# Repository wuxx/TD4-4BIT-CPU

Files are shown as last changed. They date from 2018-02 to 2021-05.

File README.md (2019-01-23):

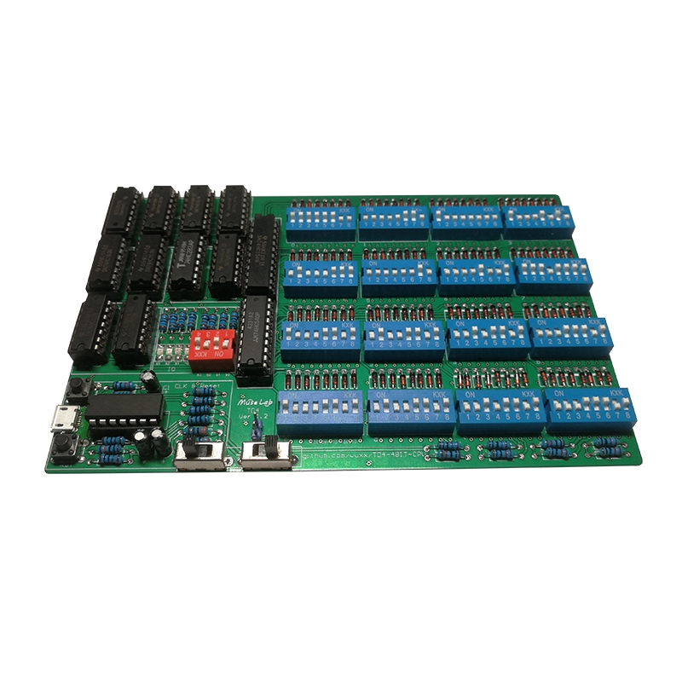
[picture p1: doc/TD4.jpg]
TD4


#### [自己动手做CPU 之 TD4 前言](https://www.bilibili.com/video/av19607028/) ####
#### [自己动手做CPU 之 TD4 原理分析0-系统综述](https://www.bilibili.com/video/av19608406/) ####
#### [自己动手做CPU 之 TD4 原理分析1-[时钟、复位]](https://www.bilibili.com/video/av19609356/) ####
#### [自己动手做CPU 之 TD4 原理分析2-[存储器、输入、输出]](https://www.bilibili.com/video/av19637295/) ####
#### [自己动手做CPU 之 TD4 原理分析3-[控制器、运算器]](https://www.bilibili.com/video/av19640430/) ####
\#LOAD0 = D6 | D7  
\#LOAD1 = #D6 | D7  
\#LOAD2 = #(#D6 & D7)  
\#LOAD3 = #(D6 & D7 & (#C | D4))  
SEL_A   = D4 | D7  
SEL_B   = D5

#### [自己动手做CPU 之 TD4 PCB及元器件](https://www.bilibili.com/video/av20360412/) ####
#### [自己动手做CPU 之 TD4 焊接测试0-说明](https://www.bilibili.com/video/av20396047/) ####
A.  先焊接尺寸小，低的元器件，再焊接高的元器件，推荐焊接顺序如下:  
    1. 发光LED，二极管1N4148，直插电阻，USB接口。  
    2. IC插座  
    3. 8位拨码开关、4位拨码开关  
    4. 按键开关，电解电容，拨动开关  

B.  注意芯片插座，8位拨码开关和4位拨码开关的焊接方向  
#### [自己动手做CPU 之 TD4 焊接测试1-[焊接]](https://www.bilibili.com/video/av20396487/) ####
#### [自己动手做CPU 之 TD4 焊接测试2-[测试]](https://www.bilibili.com/video/av20400512/) ####

#### [自己动手做CPU 之 TD4 后记](https://www.bilibili.com/video/av20401635/) ####
架构  
1. RAM  
2. 4bit -> 8bit  
3. ALU  
4. 中断  

指令  
1. 算术逻辑指令  
2. 寻址方式（立即数寻址、相对寻址、寄存器寻址等）  
3. call push pop  

reference0:  
[指令格式](https://github.com/wuxx/TD4-4BIT-CPU/blob/master/doc/instruction.md)  
[TD4套件](https://item.taobao.com/item.htm?spm=a1z10.1-c-s.w4004-21291591846.20.3ee420f8z442NM&id=586081308296)

reference1:  
https://hackaday.io/project/8442-ttl-based-4-bit-cpu  
https://hackaday.io/project/26215-td4-cpu  
http://kamakurium.com/wp-content/uploads/2016/01/cpu_td4  
http://visual6502.org/  
http://www.4004.com/

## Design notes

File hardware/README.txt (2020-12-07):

v1.3
阻焊改成黑色

v1.4
283 C0引脚默认拉低至GND，因为部分283芯片C0悬空时候会判定为1，加法运算时候会加上这个进位，导致运算错误。

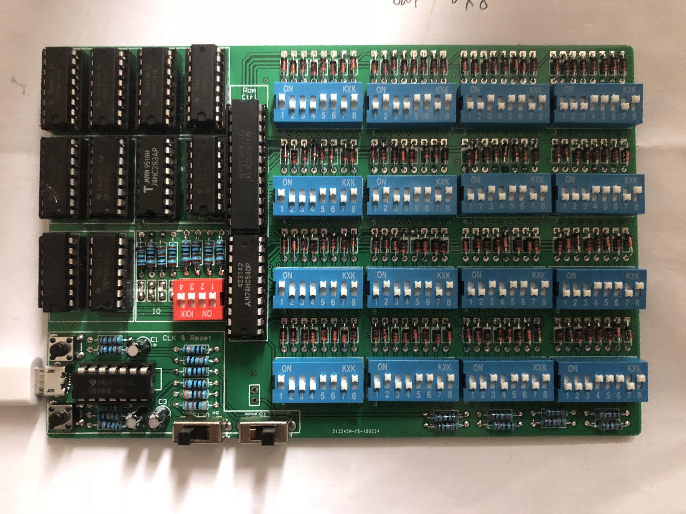
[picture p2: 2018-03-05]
doc/PCB/kit1.jpg

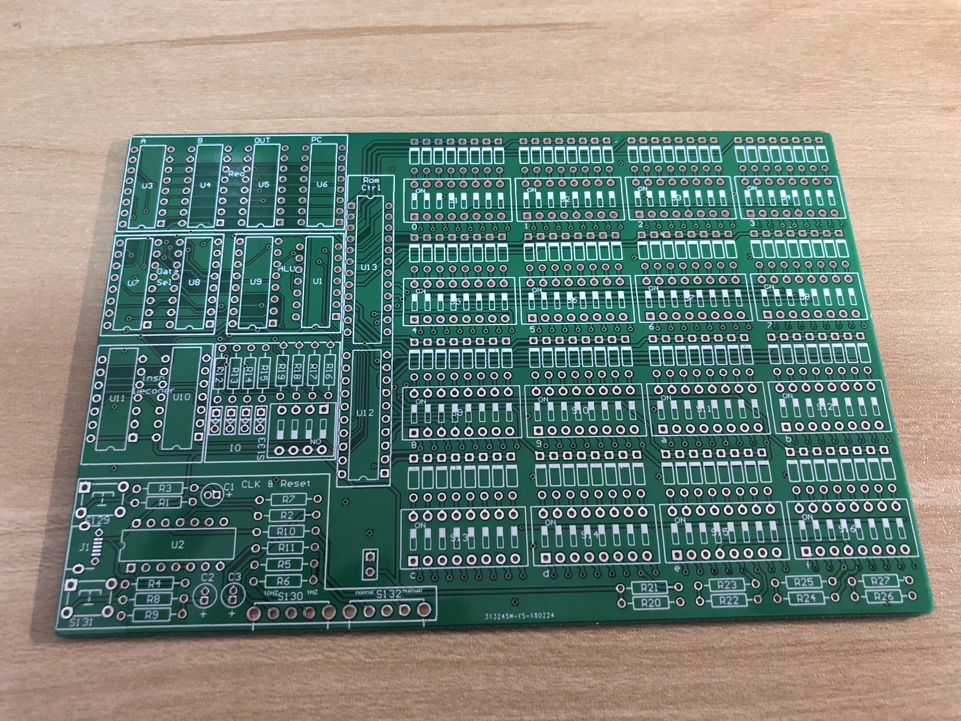
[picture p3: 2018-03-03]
doc/PCB/top.JPG

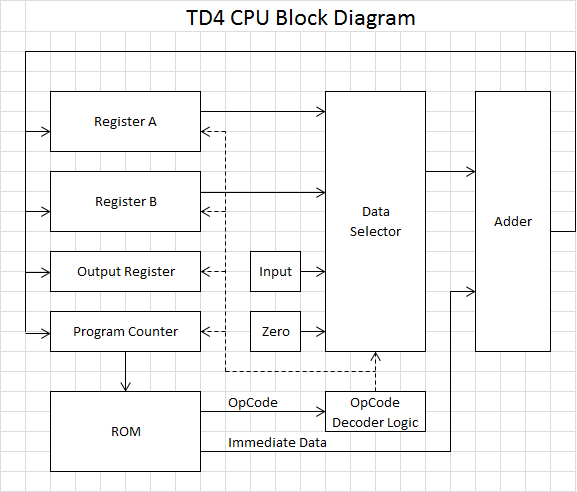
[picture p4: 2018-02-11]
doc/block diagram.png

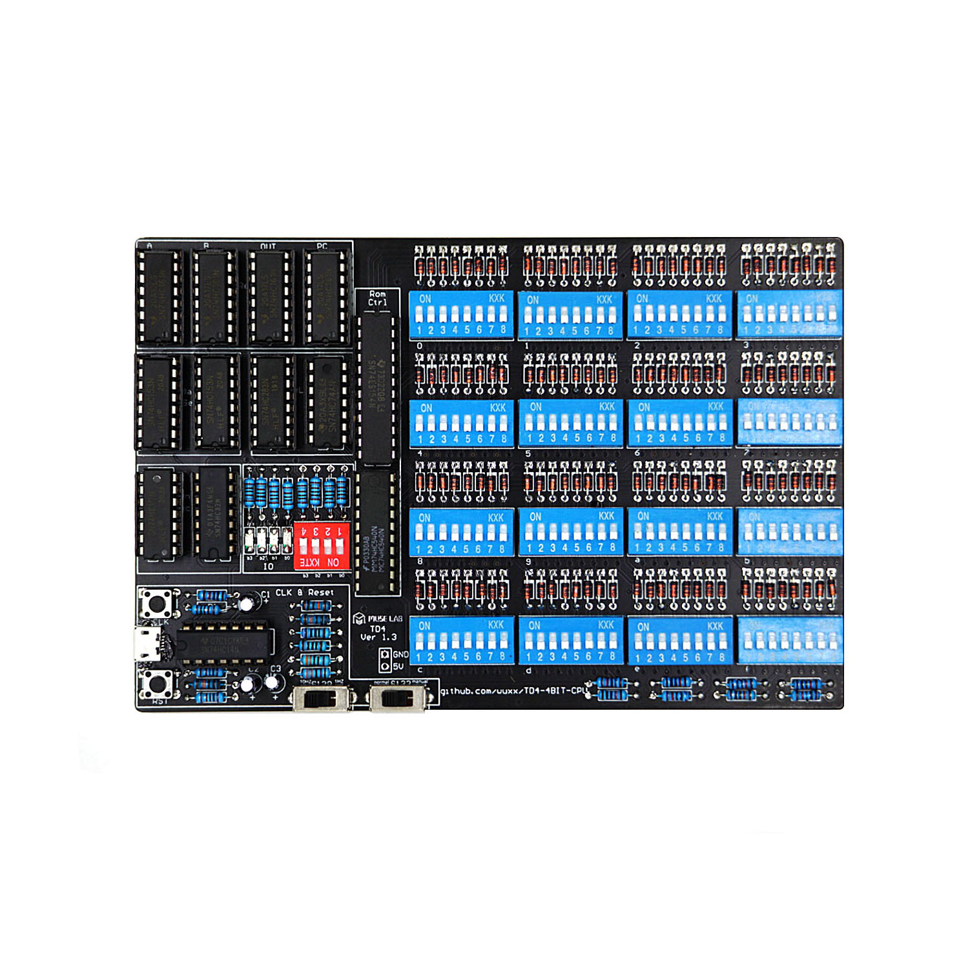
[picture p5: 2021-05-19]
doc/TD4-black-1.jpg

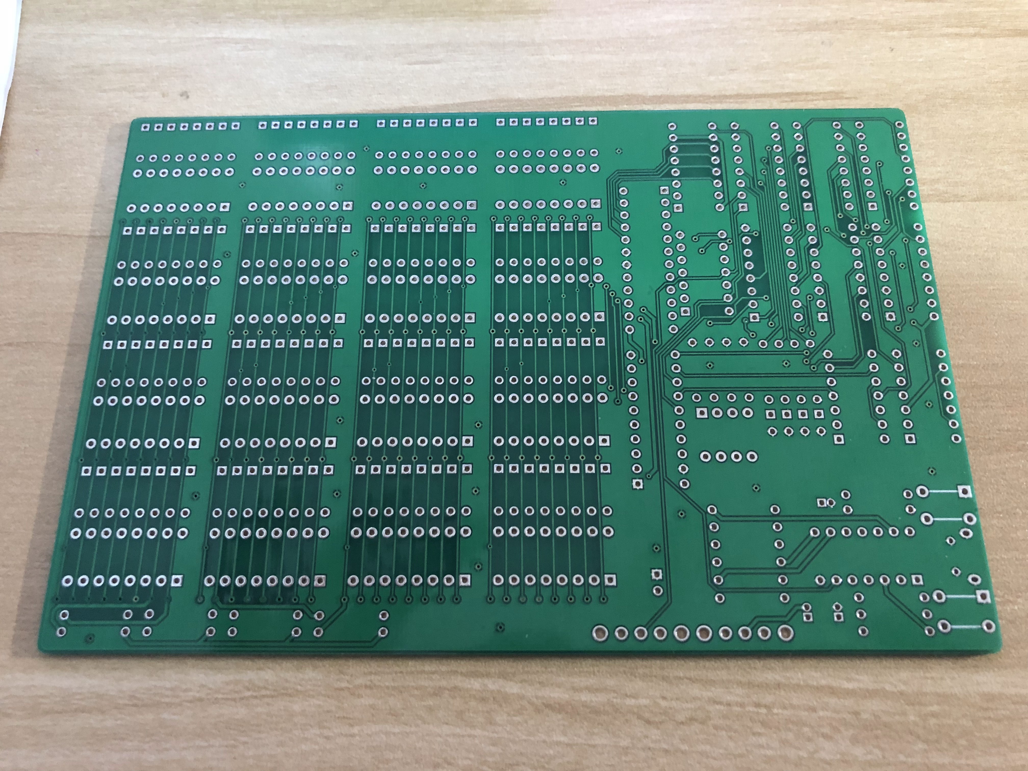
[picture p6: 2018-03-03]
doc/PCB/bottom.JPG

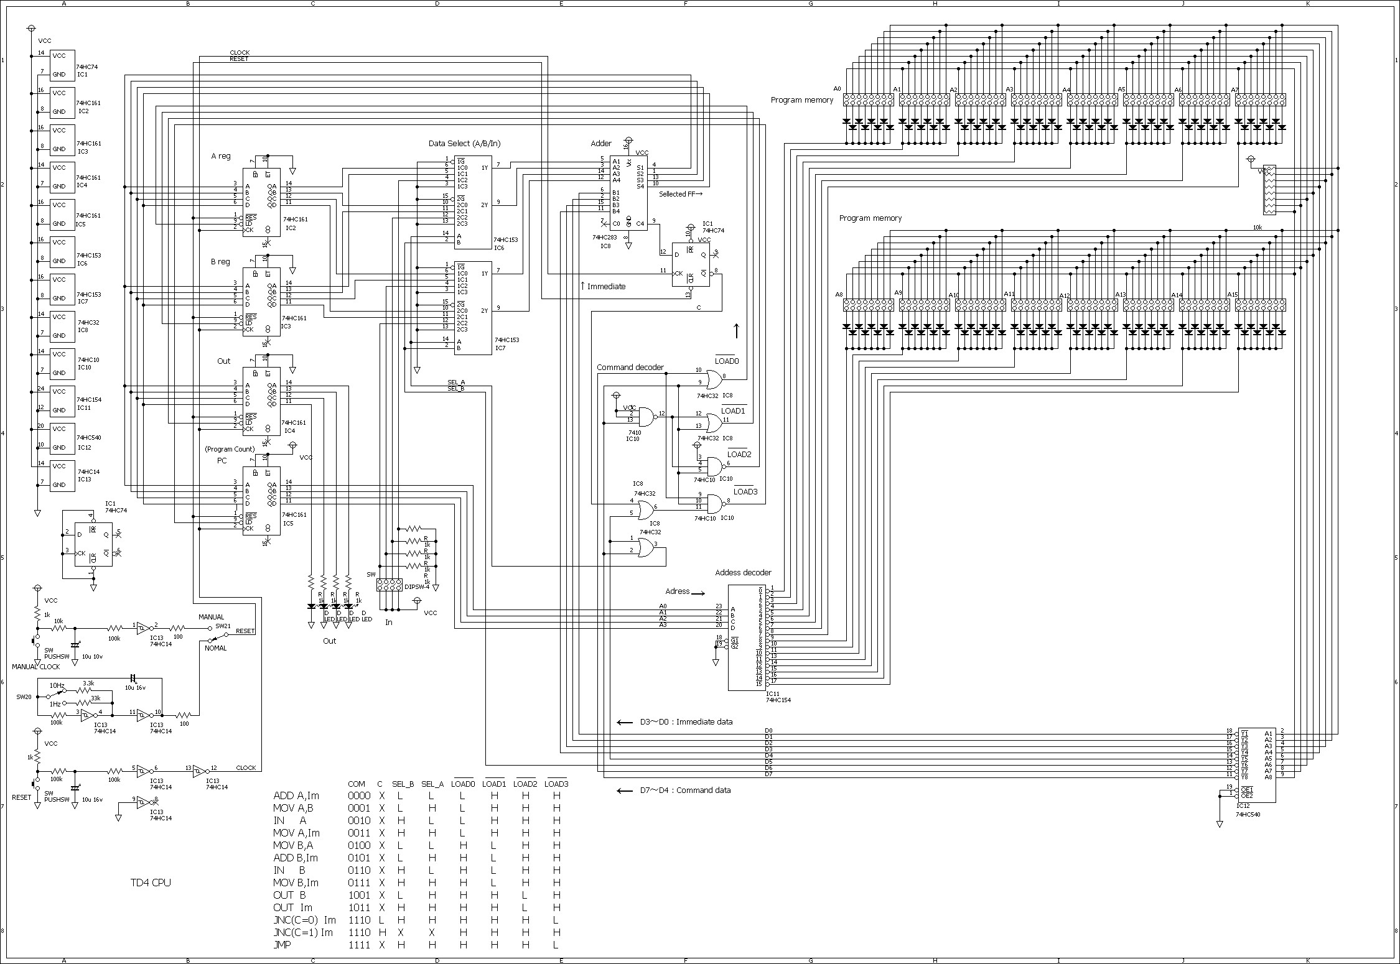
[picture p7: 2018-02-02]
doc/cpu_td4.jpg

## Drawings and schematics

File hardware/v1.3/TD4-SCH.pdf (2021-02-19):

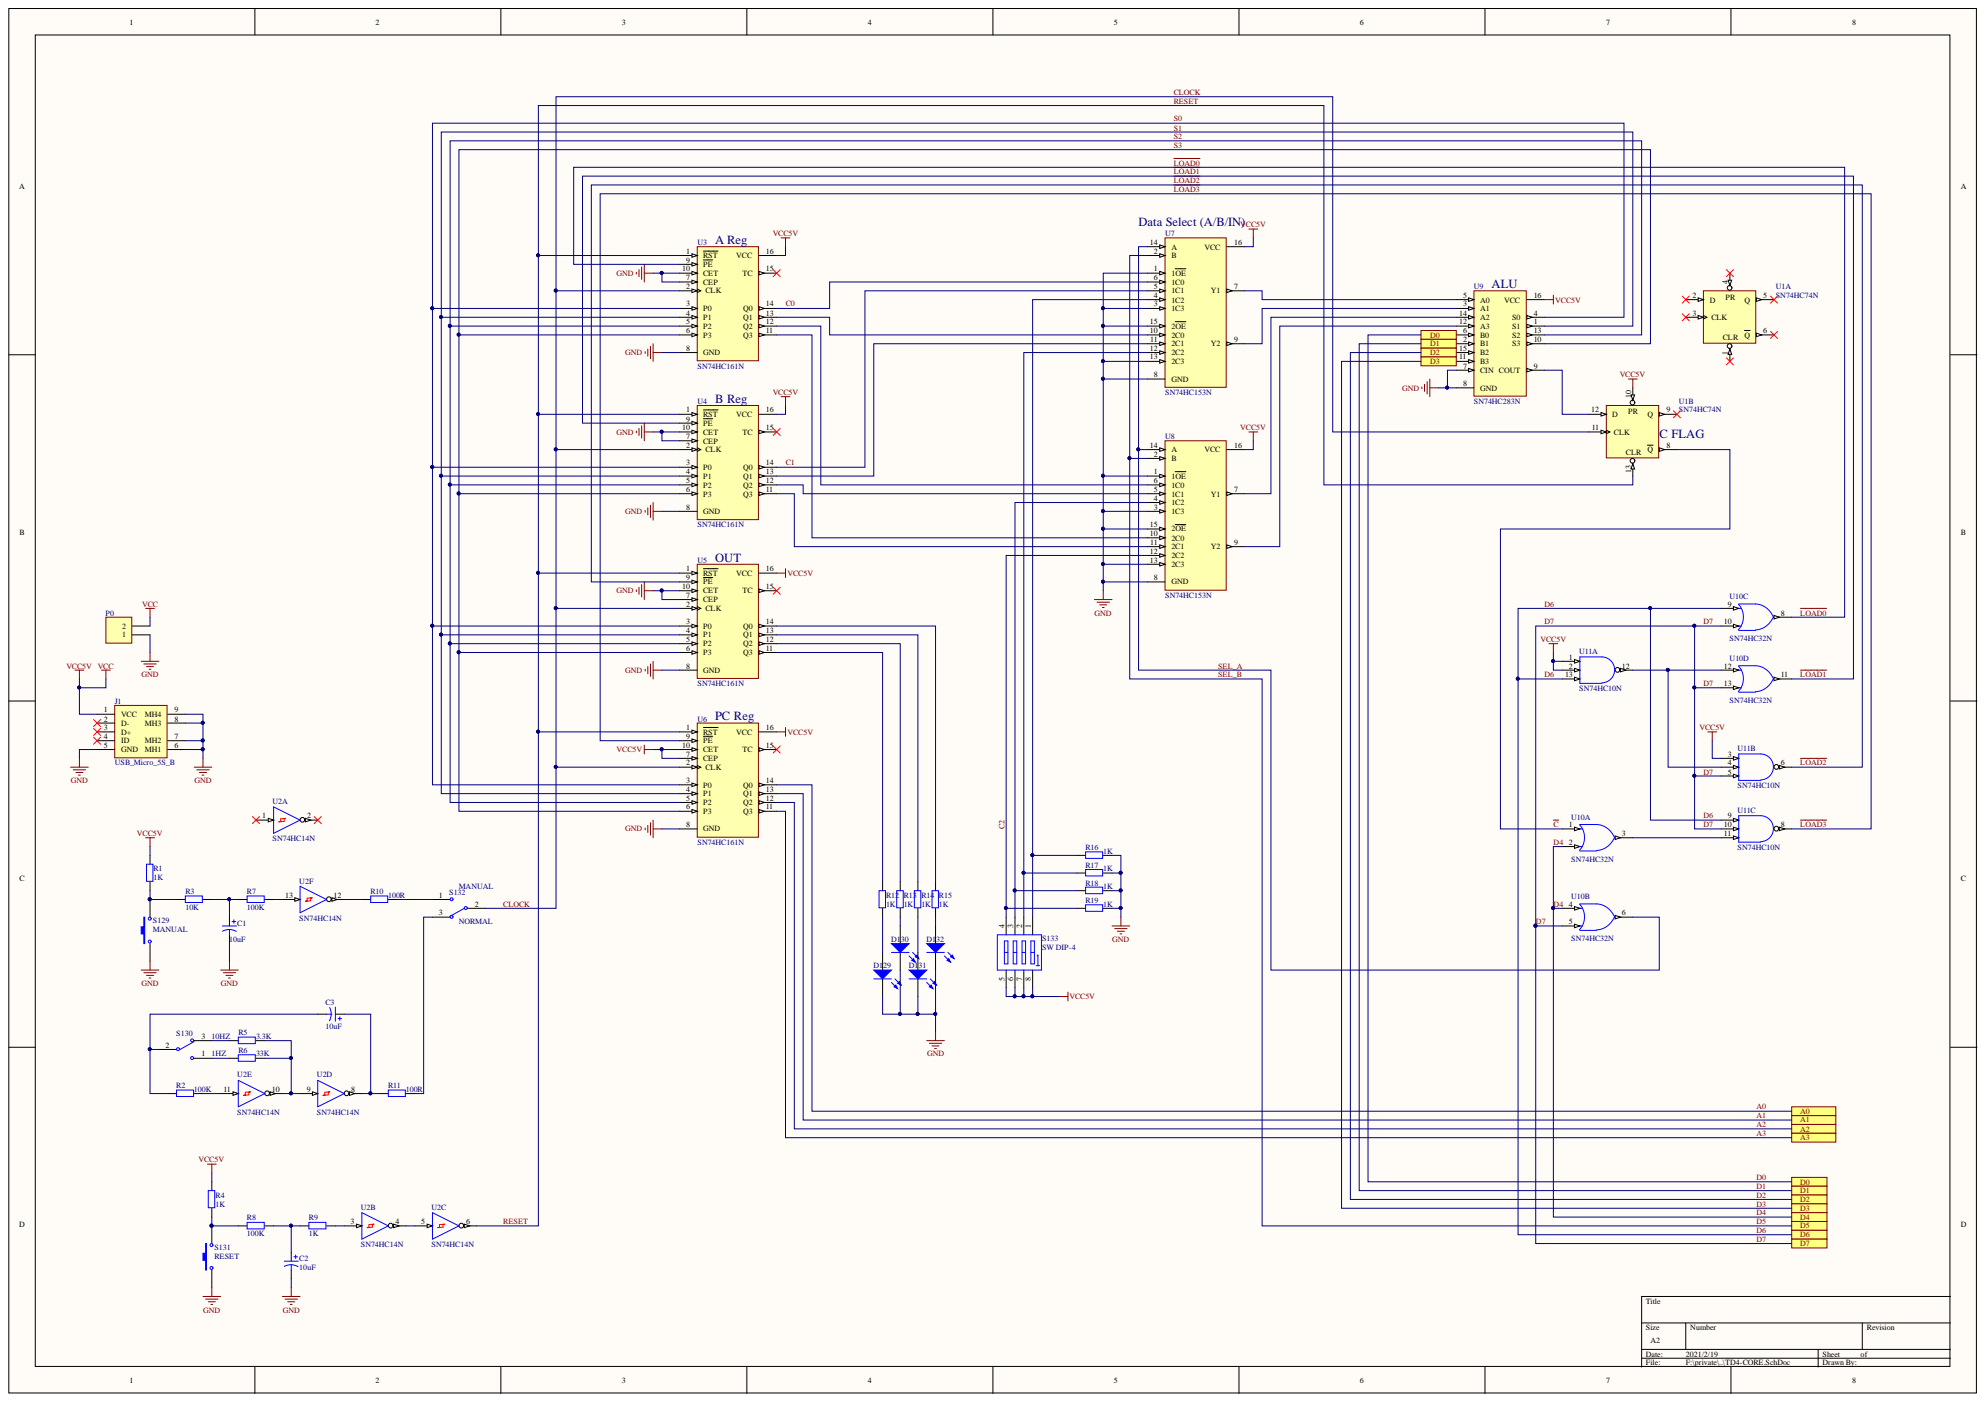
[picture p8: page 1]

S0
S1
S2
S3

LOAD0
LOAD1
LOAD2
LOAD3

Data Select (A/B/IN) VCC5V VCC5V U7 | U9 ALU

CET 10

2C1 11
2C2 12 SEL_A
2C3 13

GND 8 | 1K R16 | C 1 3 | D6 | U11C 9 8

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
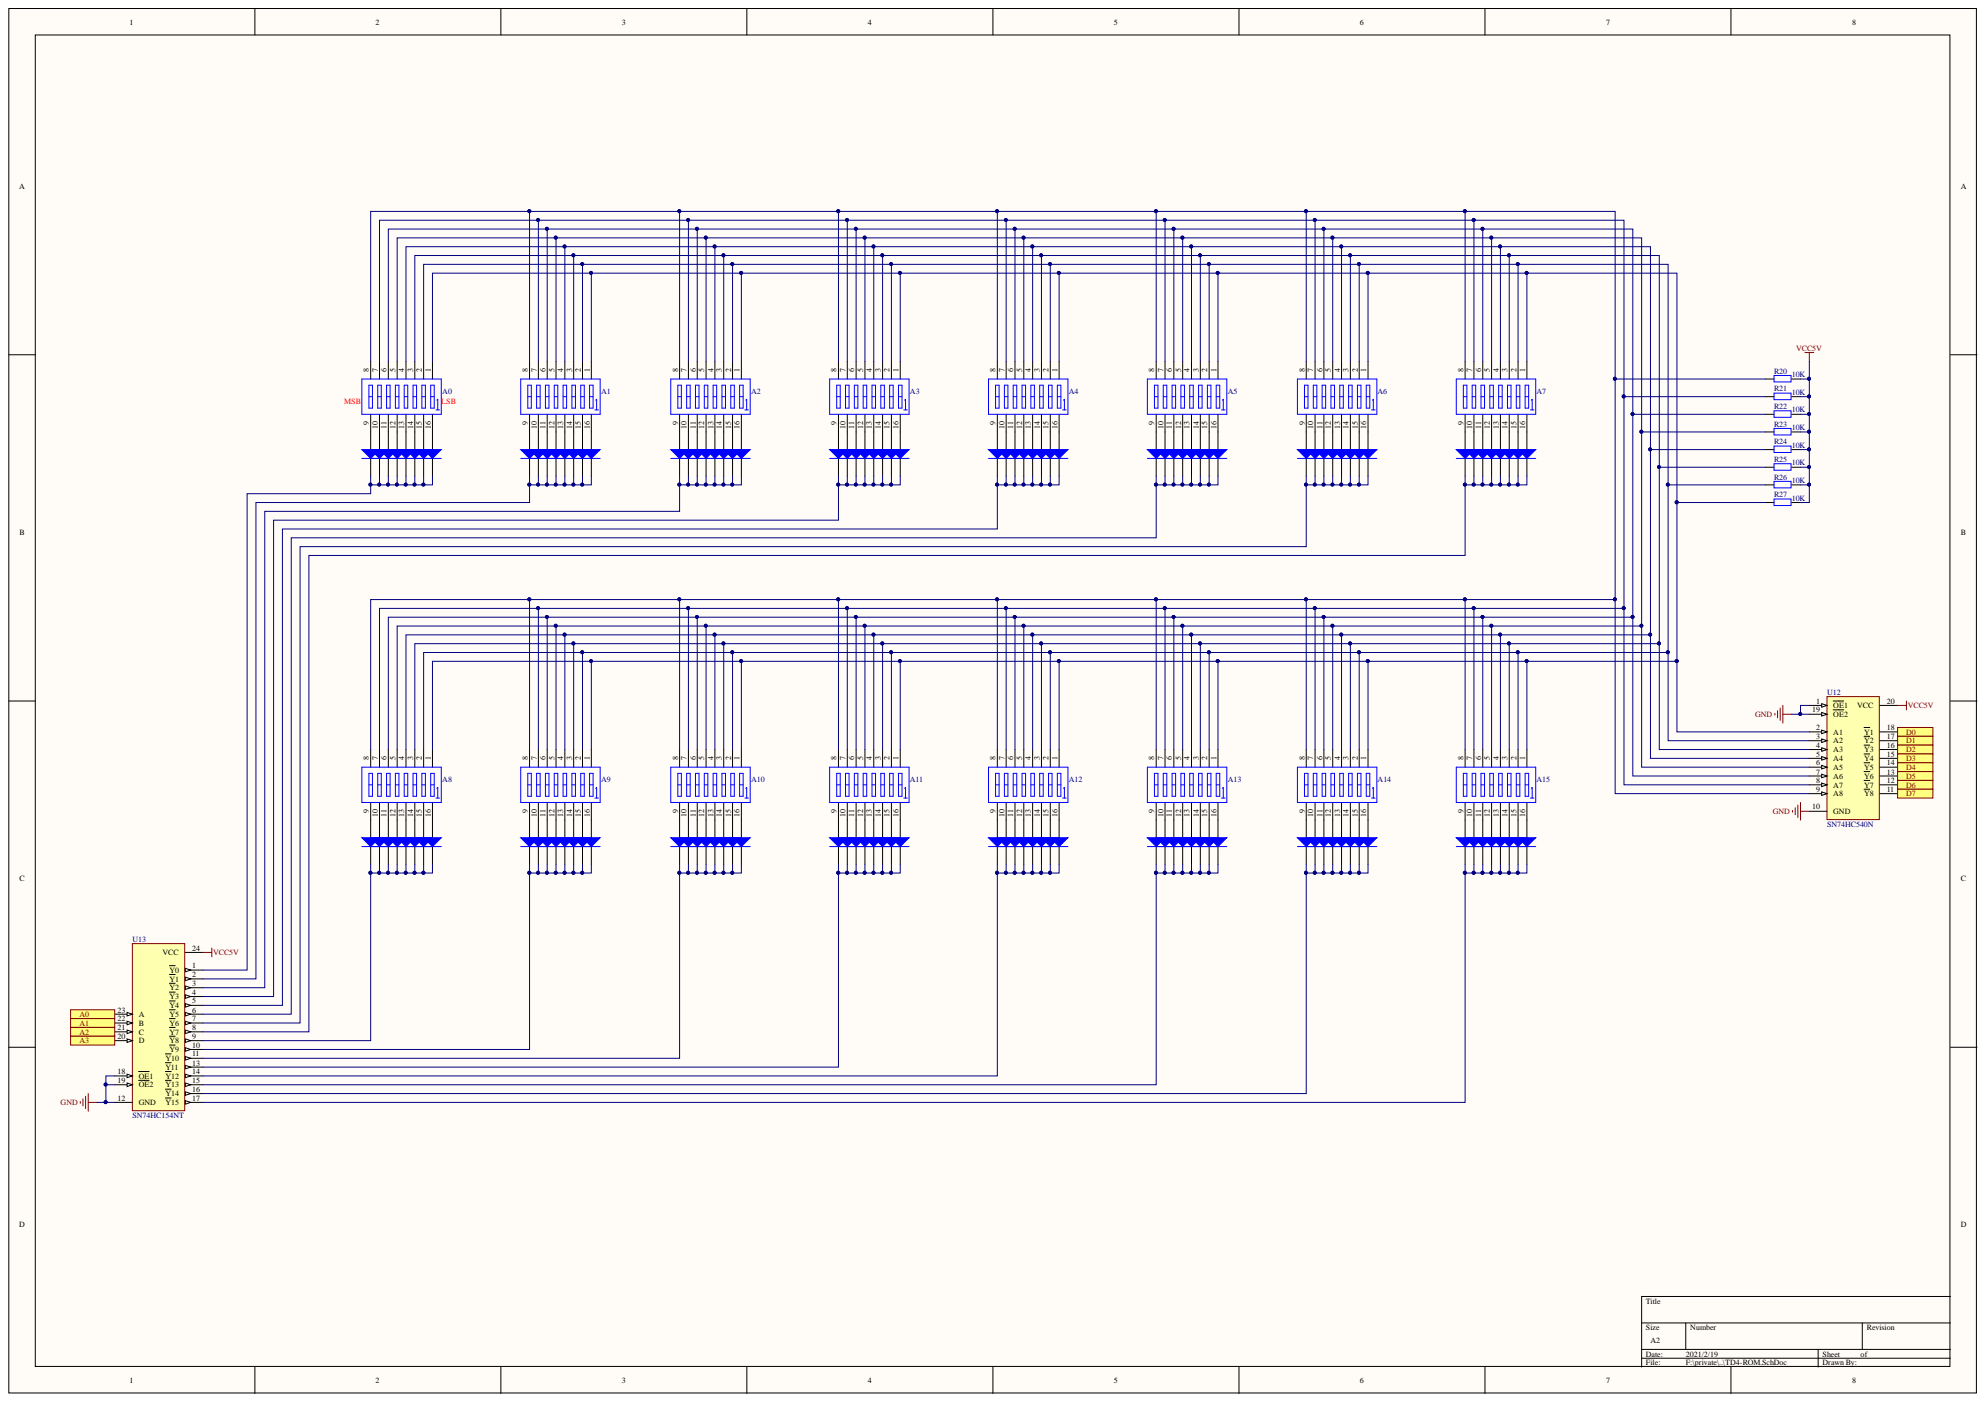
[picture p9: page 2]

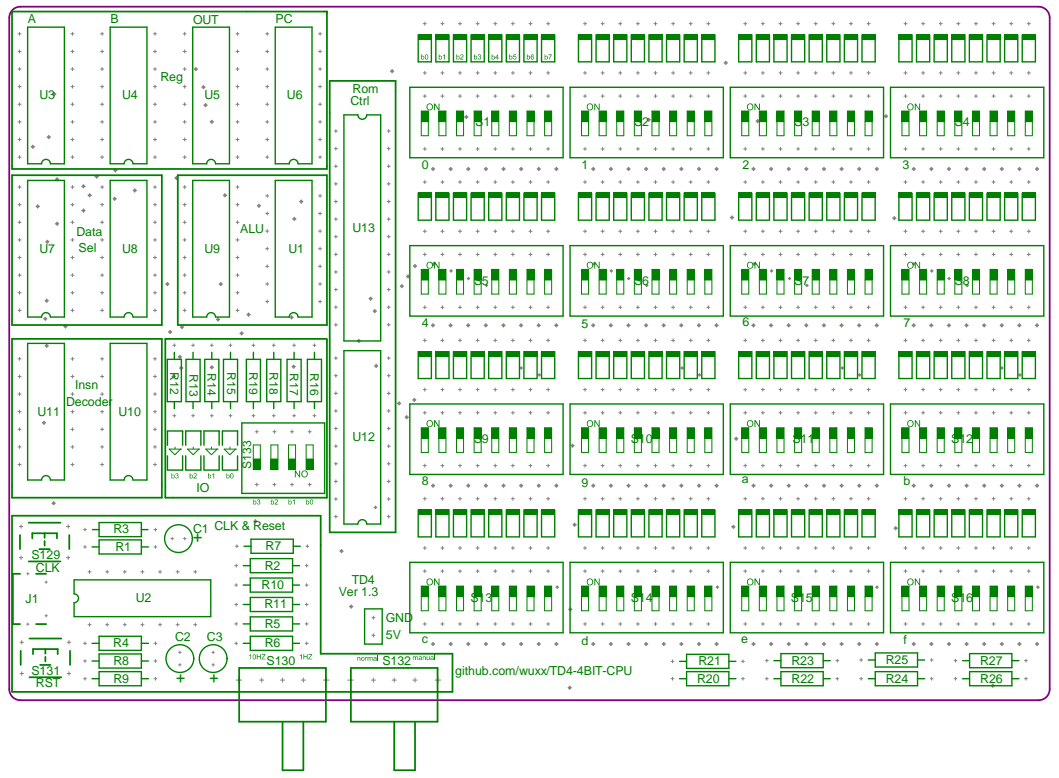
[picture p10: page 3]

github.com/wuxx/TD4-4BIT-CPU

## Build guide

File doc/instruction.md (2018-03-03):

| instruction | bit7-bit4 | bit3-bit0 | C | SEL_B | SEL_A | #LOAD0 | #LOAD1 | #LOAD2 | #LOAD3 
|:---|:---:|:---|:-:|:---:|:-----:|:-----:|:---:|:---:|:---:|
|ADD A, Im |0000 |Im |X  | L | L | L | H | H | H |
|MOV A, B |0001 |0000 |X  | L | H | L | H | H | H |
|IN  A |0010 |0000 |X  | H | L | L | H | H | H |
|MOV A, Im |0011 |Im |X  | H | H | L | H | H | H |
|MOV B, A |0100 |0000 |X  | L | L | H | L | H | H |
|ADD B, Im |0101 |Im |X  | L | H | H | L | H | H |
|IN  B |0110 |0000 |X  | H | L | H | L | H | H |
|MOV B, Im |0111 |Im |X  | H | H | H | L | H | H |
|OUT B |1001 |0000 |X  | L | H | H | H | L | H |
|OUT Im |1011 |Im |X  | H | H | H | H | L | H |
|JZ  Im |1110 |Im |L  | H | H | H | H | H | L |
|JZ  Im |1110 |Im |H  | X | X | H | H | H | H |
|JMP Im |1111 |Im |X  | H | H | H | H | H | L |

说明: SEL_B SEL_A 信号用于选择ALU的数据源，#LOAD0-#LOAD3则用于选择ALU的数据终点，说的官方一点，就是  
分别用于控制指令的源操作数和目的操作数。

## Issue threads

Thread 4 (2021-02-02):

问一下74hc74这块ic的作用是什么？

xiezhuojin, 2021-02-02:
您好，我在b站看了您的视频，这几天clone了这个repo，再看电路图的过程中发现有块74hc74的ic似乎没连到电路中去（本人在电路方面是麻瓜），所以想问一下那块ic的用处是什么？本人在这方面才疏学浅，望谅解与解答。

wuxx, 2021-02-02:
D触发器，用于FLAG输出，仔细看原理图U1A、U1B

xiezhuojin, 2021-02-02:
好的，非常感谢！

Closed 2021-02-02.

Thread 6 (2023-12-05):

Small error in doc/cpu_td4.jpg

Odie-123, 2023-12-05:
Hi,
there is a small error in the circuit diagram at doc/cpu_td4.jpg (see attached image). The NAND gate used as an inverter (IC10, 7410) is not connected to D7 but to D6. In your PowerPoint (多谐振荡器.ppt) it is drawn correctly.

Your 4-BIT CPU is a really nice and clever design!

Greetings,
Odie-123
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

wuxx, 2025-08-09:
Yes, the schematic in the hardware directory is correct, while the one in the doc directory is collected from the internet and may contain minor errors

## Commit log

2018-02-02 update hardware design.
    [TD4-CORE.SchDoc, TD4-ROM.SchDoc, TD4.PrjPcb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]
2018-03-03 1. add assembly compiler & testcase
2018-03-04 update BOM
